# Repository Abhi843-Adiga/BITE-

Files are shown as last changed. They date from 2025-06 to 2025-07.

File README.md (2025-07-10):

Bite Force Measurement Device:  
A project for a portable, ESP32-based device designed to measure bite force, intended for wellness and bio-feedback applications.

Project Overview : 

->This open-source project provides the hardware foundation for a handheld device that measures bite force using a Flexiforce sensor.   
->The data is processed by an ESP32-C3 MCU and displayed in real-time on an SPI screen.  
->The device is designed to be a portable, battery-powered,rechargable tool for non-medical, wellness-related bio-feedback and personal data tracking.

Firmware:

This repository contains the hardware design only. The firmware needs to be developed separately using platforms like the ESP-IDF or the Arduino Core for ESP32.

Core firmware tasks would include:
1.  Reading analog values from the Flexiforce sensor via the MCP6004.
2.  Converting ADC values to force units (Newtons or lbs).
3.  Driving the SPI display to show real-time readings.

Design & Development Disclaimer:

1.Hardware Status:
These PCB designs are for prototyping purposes only.
Passed Checks:
The layouts have passed basic ERC (Electrical Rules Check) and DRC (Design Rule Check).

Untested Aspects:
The designs have not been validated for Signal Integrity (SI),Power Integrity (PI), or EMI/EMC.

They are not guaranteed to pass regulatory certifications without further analysis and revisions.

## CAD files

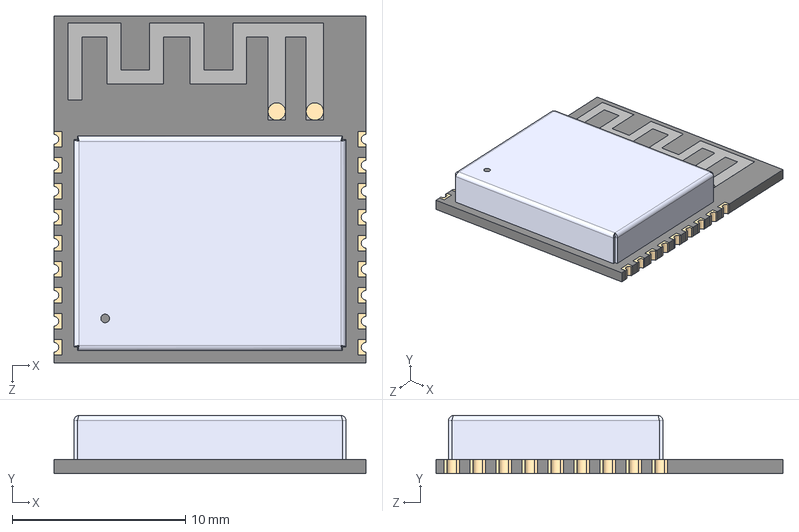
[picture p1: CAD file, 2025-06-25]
ESP32_C3_WROOM_02_N4 (1)/ESP32-C3-WROOM-02-N4.step
18.0 x 3.35 x 20.0 mm

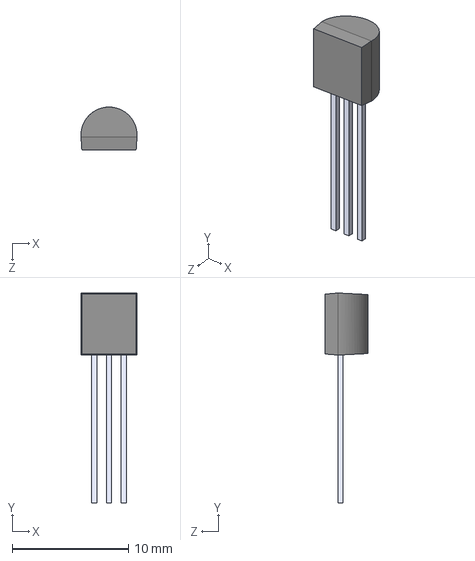
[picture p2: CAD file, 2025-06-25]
MCP1700_3302E_TO/MCP1700-3302E_TO.step
4.82 x 18.0 x 3.68 mm

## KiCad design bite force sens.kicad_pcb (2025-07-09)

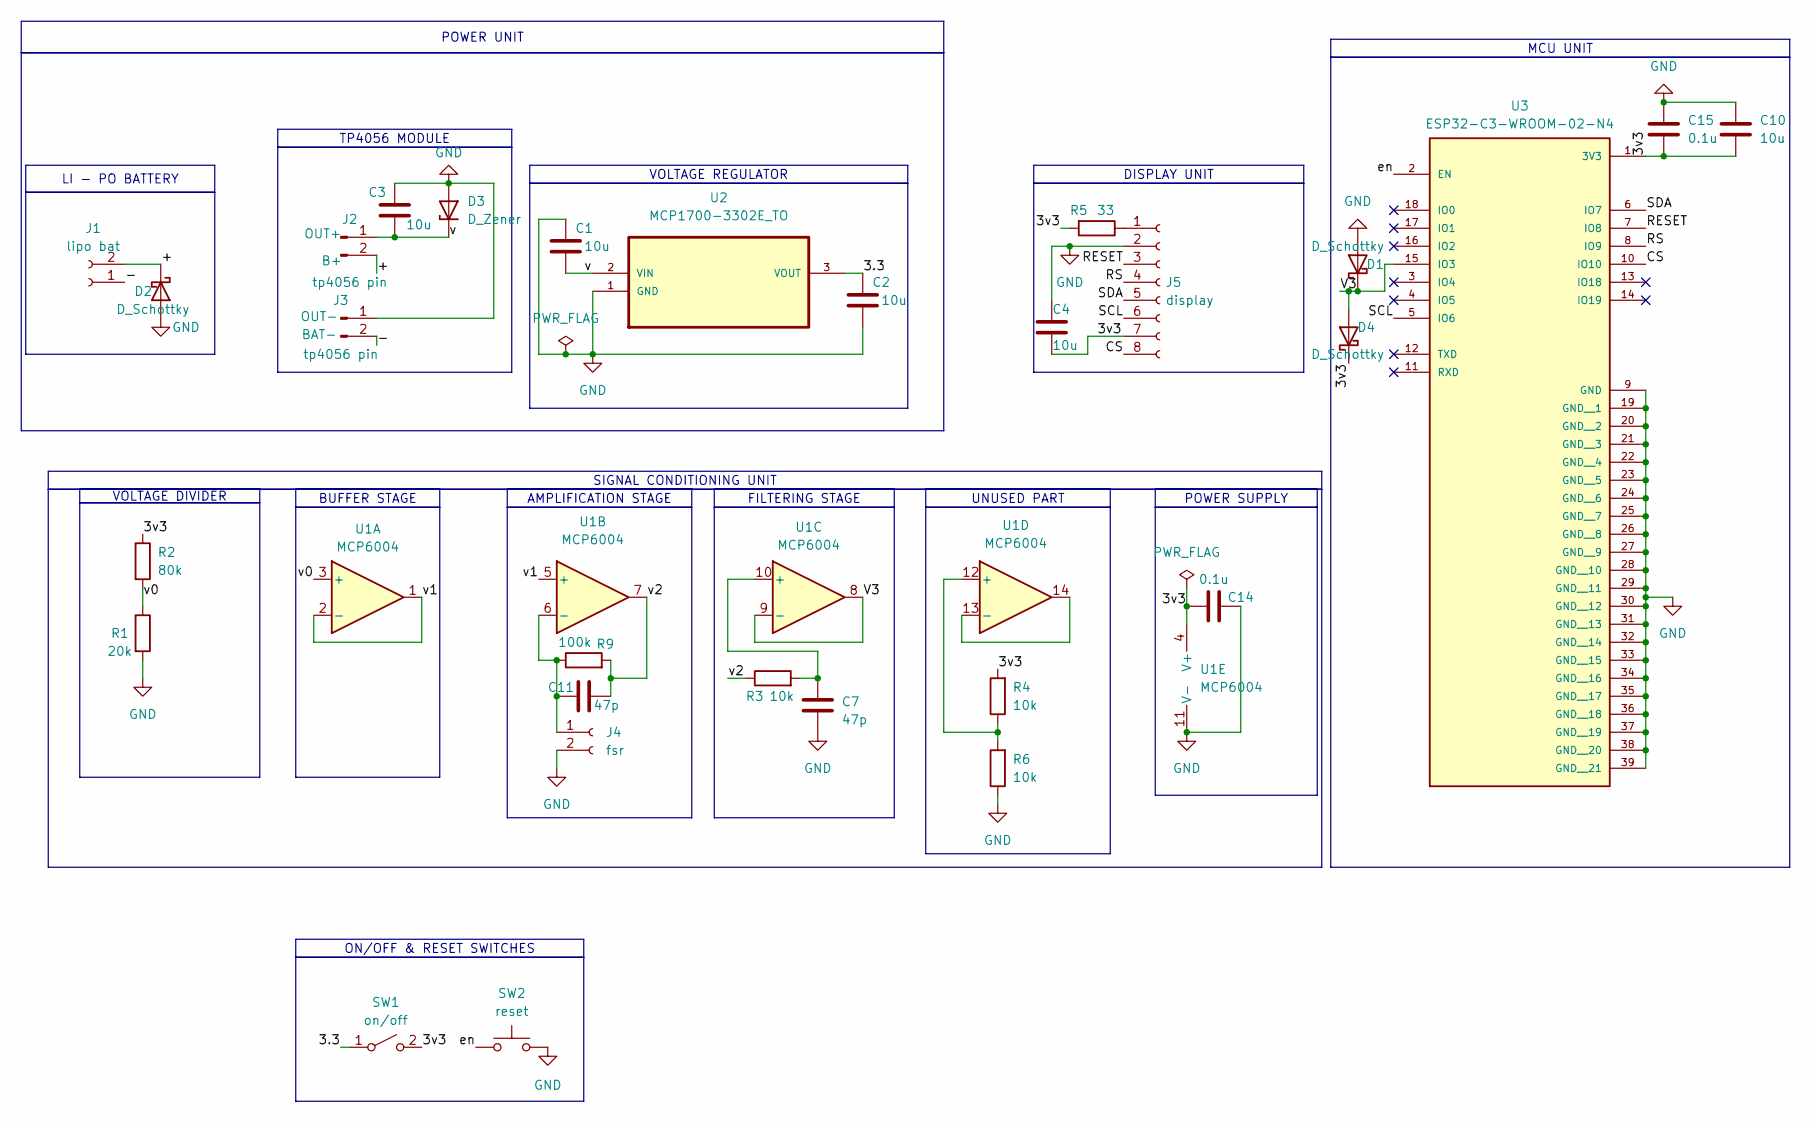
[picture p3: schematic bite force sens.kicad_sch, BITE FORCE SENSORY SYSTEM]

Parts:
C1, C2, C3, C4, C10: 10u; C_0805_2012Metric
C7, C11: 47p; C_0805_2012Metric
C14, C15: 0.1u; C_0805_2012Metric
D1, D2, D4: D_Schottky; D_SMA
D3: D_Zener; D_SMA
J1: lipo bat; JWT_A3963_1x02_P3.96mm_Vertical
J2, J3: tp4056 pin; PinHeader_1x02_P2.54mm_Vertical
J4: fsr; JST_PH_B2B-PH-K_1x02_P2.00mm_Vertical
J5: display; Hirose_FH12-8S-0.5SH_1x08-1MP_P0.50mm_Horizontal
R1: 20k; R_0805_2012Metric
R2: 80k; R_0805_2012Metric
R3, R4, R6: 10k; R_0805_2012Metric
R5: 33; R_0805_2012Metric
R9: 100k; R_0805_2012Metric
SW1: on/off; SW_DIP_SPSTx01_Slide_6.7x4.1mm_W6.73mm_P2.54mm_LowProfile_J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
SW2: reset; SW_PUSH_6mm
U1: MCP6004; SOIC-14_3.9x8.7mm_P1.27mm
U2: MCP1700-3302E_TO; TO127P254X495-3; MPN MCP1700-3302E/TO
U3: ESP32-C3-WROOM-02-N4; MODULE_ESP32-C3-WROOM-02-H4

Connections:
/3.3: C2.1, SW1.1 (A), U2.3 (VOUT)
/3v3: C4.2, C10.2, C14.1, C15.2, D4.1 (K), J5.7, R2.1, R4.2, R5.2, SW1.2 (B), U1.4 (V+), U3.1 (3V3)
/+: D2.1 (K), J1.2, J2.2
/-: J1.1, J3.2
/CS: J5.8, U3.10 (IO10)
/RESET: J5.3, U3.7 (IO8)
/RS: J5.4, U3.8 (IO9)
/SCL: J5.6, U3.5 (IO6)
/SDA: J5.5, U3.6 (IO7)
/V3: D1.1 (K), D4.2 (A), U1.8, U1.9 (-), U3.15 (IO3)
/en: SW2.1, U3.2 (EN)
/v: C1.2, C3.2, D3.1 (K), J2.1, U2.2 (VIN)
/v0: R1.1, R2.2, U1.3 (+)
/v1: U1.1, U1.2 (-), U1.5 (+)
/v2: C11.2, R3.1, R9.2, U1.7
GND: C1.1, C2.2, C3.1, C4.1, C7.2, C10.1, C14.2, C15.1, D1.2 (A), D2.2 (A), D3.2 (A), J3.1, J4.2, J5.2, R1.2, R6.1, SW2.2, U1.11 (V-), U2.1 (GND), U3.9 (GND), U3.19 (GND__1), U3.20 (GND__2), U3.21 (GND__3), U3.22 (GND__4), U3.23 (GND__5), U3.24 (GND__6), U3.25 (GND__7), U3.26 (GND__8), U3.27 (GND__9), U3.28 (GND__10), U3.29 (GND__11), U3.30 (GND__12), U3.31 (GND__13), U3.32 (GND__14), U3.33 (GND__15), U3.34 (GND__16), U3.35 (GND__17), U3.36 (GND__18), U3.37 (GND__19), U3.38 (GND__20), U3.39 (GND__21)
unnamed: C11.1, J4.1, R9.1, U1.6 (-)
unnamed: J5.1, R5.1
unnamed: C7.1, R3.2, U1.10 (+)
unnamed: R4.1, R6.2, U1.12 (+)
unnamed: U1.13 (-), U1.14

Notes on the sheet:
LI - PO BATTERY
POWER UNIT
MCU UNIT
TP4056 MODULE
UNUSED PART
FILTERING STAGE
DISPLAY UNIT
SIGNAL CONDITIONING UNIT
VOLTAGE REGULATOR
VOLTAGE DIVIDER
ON/OFF & RESET SWITCHES
POWER SUPPLY
BUFFER STAGE
AMPLIFICATION STAGE

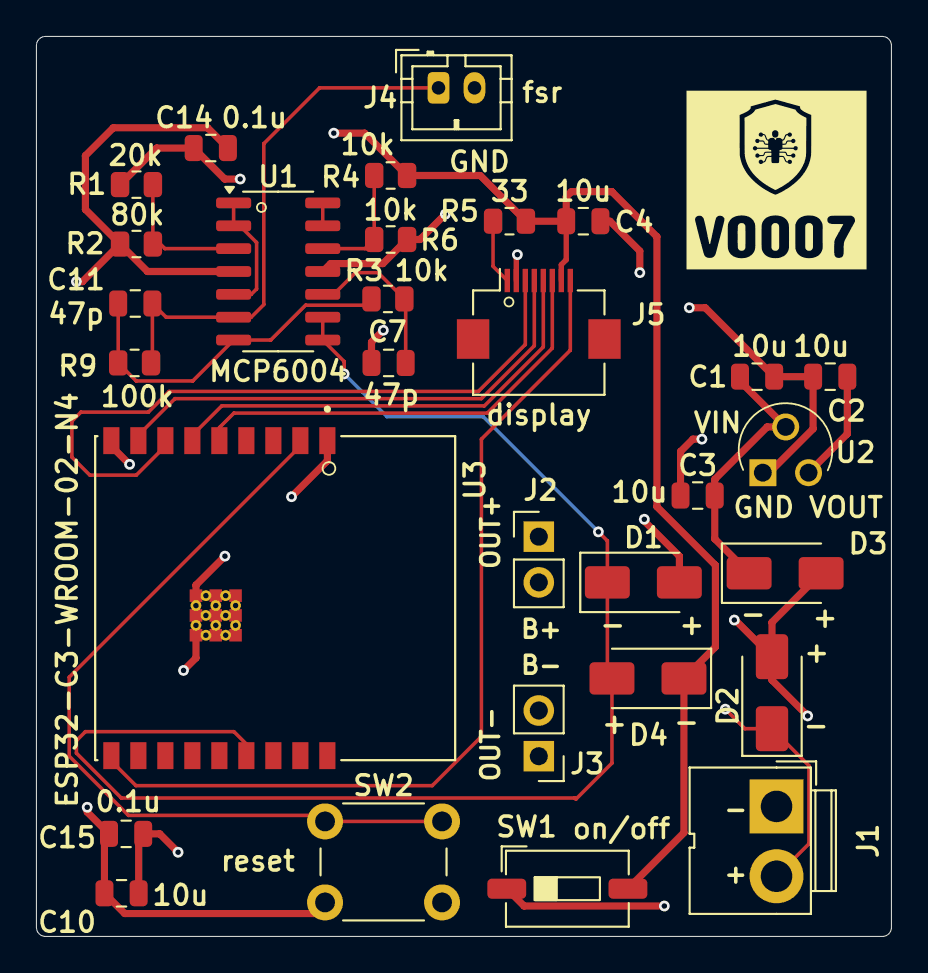
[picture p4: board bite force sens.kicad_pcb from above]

Board: 4 copper layers, 47.5 x 50.0 mm, 30 parts (0 on the bottom side), 21 nets.

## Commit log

2025-06-18 added ressitor
    [bite force sens.kicad_sch]
2025-06-18 added ressitor again
    [bite force sens.kicad_sch]
2025-06-18 removed un
    [bite force sens.kicad_sch]
2025-06-18 Update bite force sens.kicad_sch
    [bite force sens.kicad_sch]
2025-06-24 bite force sensor sample is completed start of fine tuning after this
    [bite force sens.kicad_pcb, bite force sens.kicad_sch]
2025-06-25 made entire change in design and now the fresh pcb will be done and comitted at next commit
    [ESP32-C3-WROOM-02-N4.step, MCP1700-3302E_TO.step, bite force sens.kicad_pcb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]
2025-06-27 completed the pcb design
    [bite force sens.kicad_pcb, bite force sens.kicad_sch, bite force sens.step]
2025-06-27 plotted some gerber files
    [bite force sens.kicad_pcb]
2025-07-09 Changed the pcb to 4layer since the mcu is used and this is just the model without looking for the SI/PI,EMC/EMI
    [bite force sens.kicad_pcb]
